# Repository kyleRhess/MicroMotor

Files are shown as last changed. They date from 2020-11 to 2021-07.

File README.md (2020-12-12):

# MicroMotor

## A three-phase BLDC motor driver with a rotary encoder interface and serial communication via USB.
## [More project details can be found here.](https://kylerhess.github.io/umotor.html)
\
 This code has been written for and tested on an ARM STM32F410 processor.
\
\
The rotary encoder interface was originally developed in my [EncoderQ](https://github.com/kyleRhess/EncoderQ) project.
\
\
The only rotary encoder that has been tested so far is the [Omron E6D-C](http://www.ia.omron.com/data_pdf/cat/e6d-c_ds_e_5_1_csm497.pdf).
\
\
The only BLDC motor that has been tested so far is the [Maxon EC 339268](https://www.maxongroup.com/medias/sys_master/root/8841185394718/EN-282.pdf). The motor requirement is that it must include Hall sensor output for position sensing. Back-EMF control is not currently supported.

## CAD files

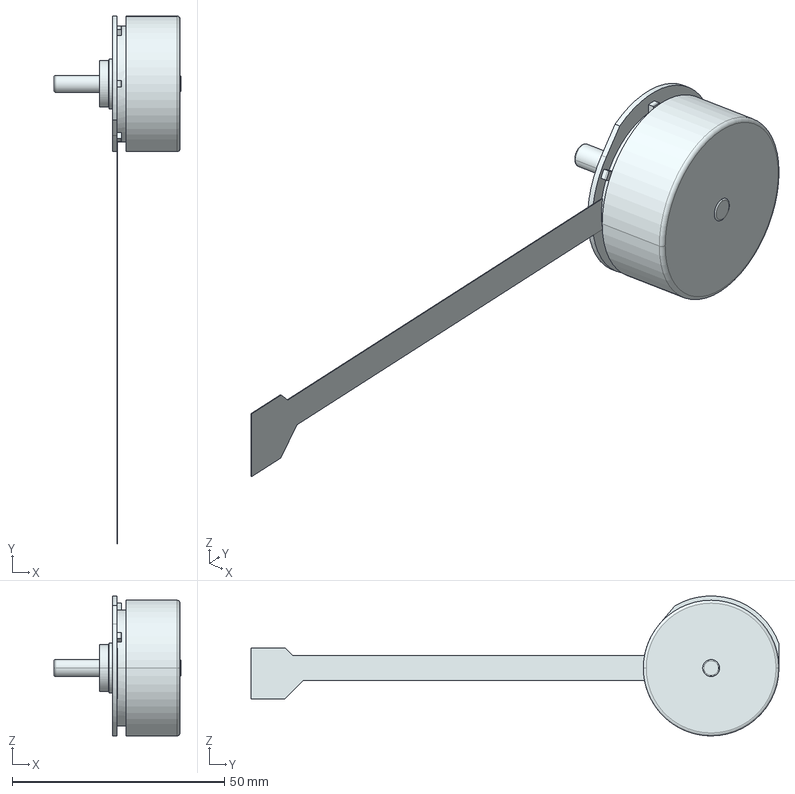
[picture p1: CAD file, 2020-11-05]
339267-ec32fl-15w-a/339267_ec32fl_15w_a.stp
29.9 x 124.5 x 33.0 mm

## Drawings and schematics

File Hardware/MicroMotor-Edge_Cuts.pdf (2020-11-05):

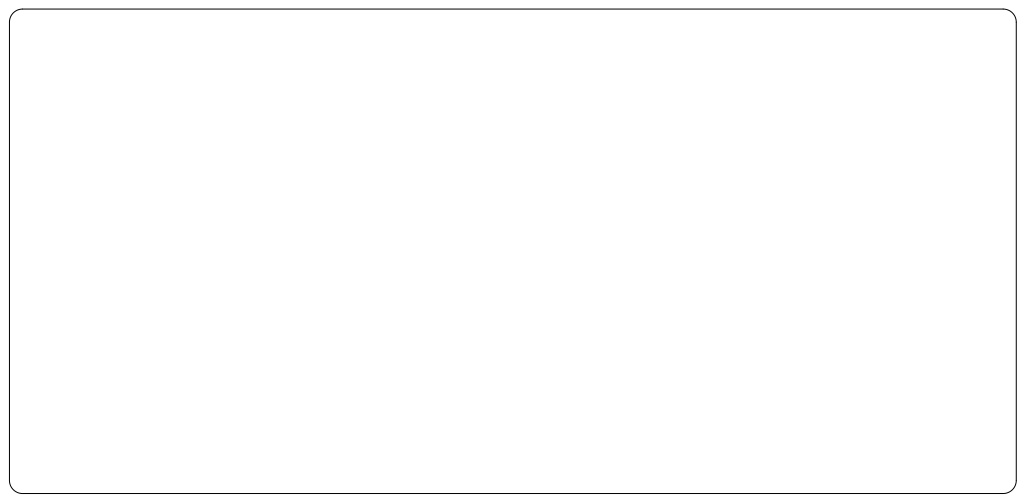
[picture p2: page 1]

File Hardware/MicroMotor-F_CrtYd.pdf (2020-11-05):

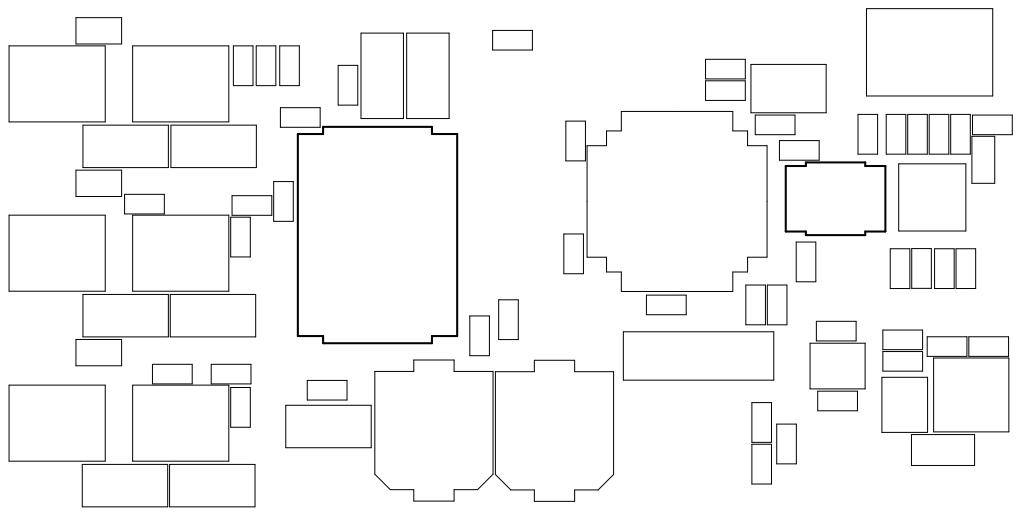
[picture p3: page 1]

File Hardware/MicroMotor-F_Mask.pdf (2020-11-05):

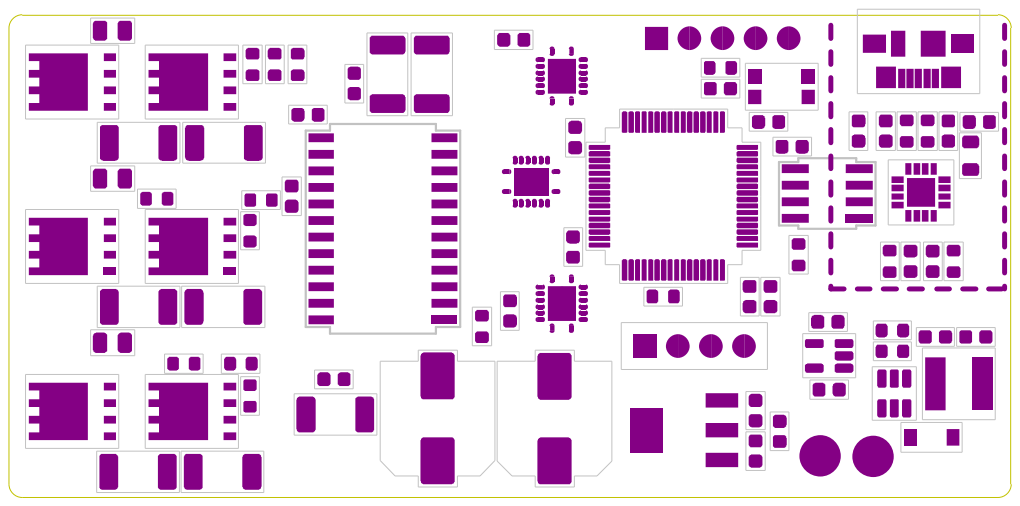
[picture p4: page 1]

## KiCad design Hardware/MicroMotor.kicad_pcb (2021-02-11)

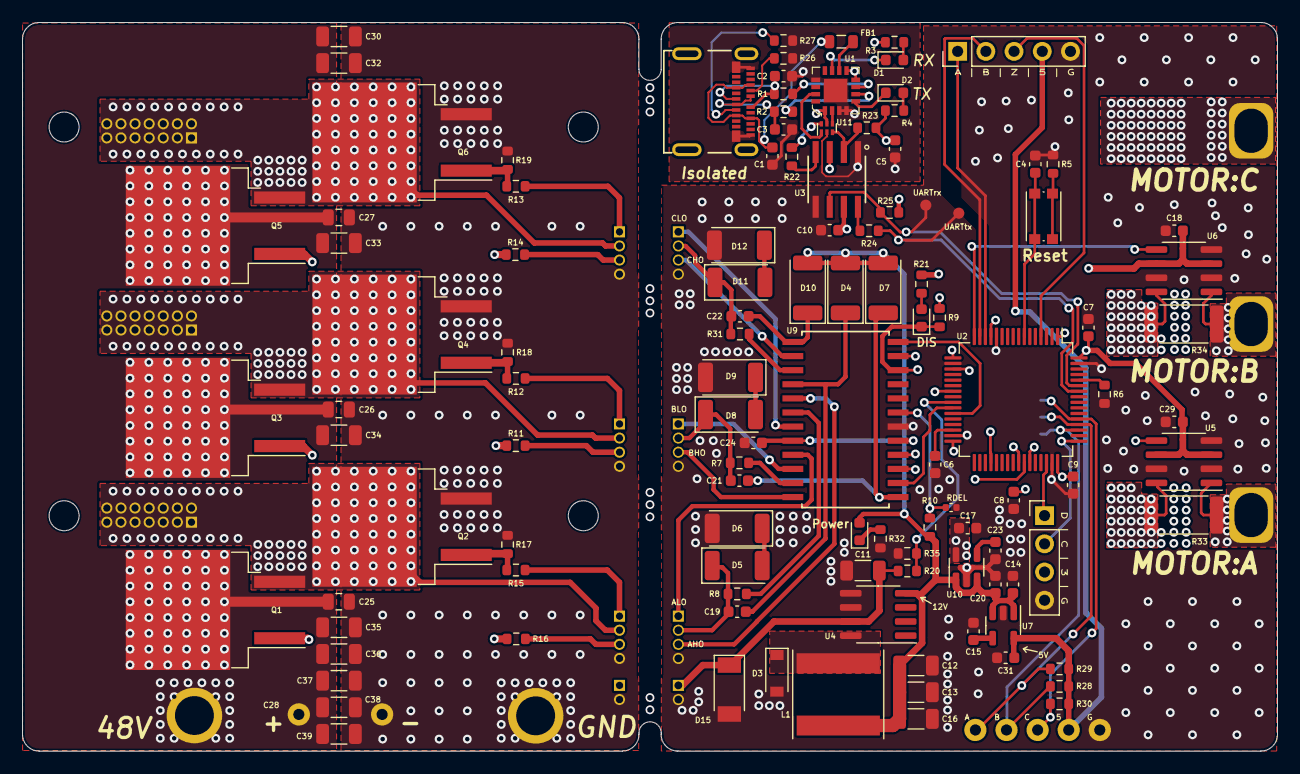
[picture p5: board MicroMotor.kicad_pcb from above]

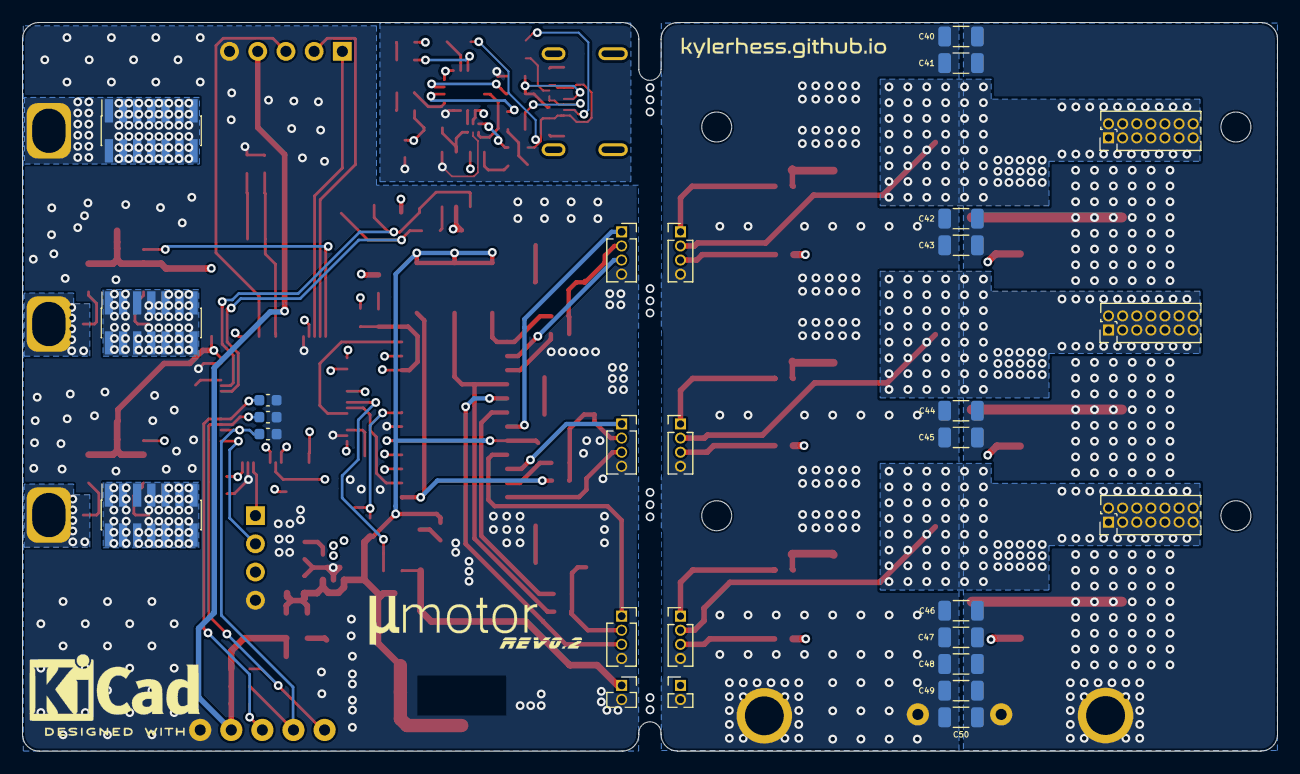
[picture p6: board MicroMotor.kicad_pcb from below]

Board: 4 copper layers, 113.0 x 65.6 mm, 149 parts (28 on the bottom side), 81 nets.

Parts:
5: TestPoint_Loop_D2.50mm_Drill1.0mm
48V: TestPoint_THTPad_D4.0mm_Drill2.0mm
A: TestPoint_Plated_Hole_D3.0mm
A#2: TestPoint_Loop_D2.50mm_Drill1.0mm
B: TestPoint_Plated_Hole_D3.0mm
B#2: TestPoint_Loop_D2.50mm_Drill1.0mm
C: TestPoint_Plated_Hole_D3.0mm
C1, C9, C15, C23: 10nF; C_0603_1608Metric
C2, C3: 47pF; C_0603_1608Metric
C4, C5, C8, C10, C18, C29: 0.1uF; C_0603_1608Metric
C6, C7: 2.2uF; C_0603_1608Metric
C11: 1uF; C_1206_3216Metric
C12, C13, C16: 47uF; C_1206_3216Metric
C14, C17, C20, C24, C31: 1uF; C_0603_1608Metric
C19, C21, C22: 0.22uF; C_0603_1608Metric
C25, C26, C27: 1uF; C_0805_2012Metric
C28: 1000uF; C_Radial_D18.0mm_H35.5mm_P7.50mm
C30, C32, C33, C34, C35, C36, C37, C38, C39, C40, C41, C42, C43, C44, C45, C46, C47, C48, C49, C50: 4.7uF; C_1206_3216Metric
C#2: TestPoint_Loop_D2.50mm_Drill1.0mm
D1, D2, D13, D14: LED; LED_0603_1608Metric
D3: 60V 500mA; D_SOD-123
D4, D5, D6, D7, D8, D9, D10, D11, D12: D; D_2010_5025Metric
D15: SMA6S56A; D_SOD-128
FB1: 1.5A; L_0805_2012Metric
G: TestPoint_Loop_D2.50mm_Drill1.0mm
GND: TestPoint_THTPad_D4.0mm_Drill2.0mm
J1: USB_C_Receptacle_USB2.0; USB_C_1054500101
J2: Conn_01x04_Male; PinHeader_1x04_P2.54mm_Vertical
J3: Conn_01x05_Male; PinHeader_1x05_P2.54mm_Vertical
J4, J5, J6: Conn_01x04_Male; PinHeader_1x04_P1.27mm_Vertical
J7, J8, J9: Conn_02x06_Odd_Even; PinHeader_2x07_P1.27mm_Vertical
J10, J11, J12: Conn_02x06_Odd_Even; PinSocket_2x07_P1.27mm_Vertical_SMD
J13, J14, J15: Conn_01x04_Female; PinSocket_1x04_P1.27mm_Vertical
J16: Conn_01x02_Male; PinHeader_1x02_P1.27mm_Vertical
J17: Conn_01x02_Female; PinSocket_1x02_P1.27mm_Vertical
L1: 100uH; L_Taiyo-Yuden_NR-80xx
Q1, Q2, Q3, Q4, Q5, Q6: FDB075N15A; TO-263-2
R1, R2: 27; R_0603_1608Metric
R3, R4, R21, R22, R24: 330; R_0603_1608Metric
R5: 470; R_0603_1608Metric
R6, R20, R28, R29, R30, R32: 10k; R_0603_1608Metric
R7, R8, R31: 1.2; R_0603_1608Metric
R9, R17, R18, R19: 100k; R_0603_1608Metric
R10: 50k; R_0603_1608Metric
R11, R12, R13, R14, R15, R16: 22; R_0603_1608Metric
R23, R25: 1k; R_0603_1608Metric
R26, R27: 5.1k; R_0603_1608Metric
R33, R34: 750u; R_2512_6332Metric
R35: 576; R_0603_1608Metric
RDEL: C_0402_1005Metric
SW1: SW_Push; SW_Push_1P1T_NO_CK_KMR2
U1: FT230XQ-T; WQFN-16-1EP_4x4mm
U2: STM32F410RBTx; LQFP-64_10x10mm_P0.5mm
U3: ACSL-6210-00RE
U4: LM2594HVM-12; SOIC-8_3.9x4.9mm_P1.27mm
U5, U6: INA240A3D; SOIC-8_3.9x4.9mm_P1.27mm
U7: LP2985-5.0; SOT-23-5
U9: HIP4086ABZ
U10: LP2985-3.3; SOT-23-5
U11: NC7WZ04; Fairchild_MicroPak-6_1.0x1.45mm_P0.5mm
UARTrx: TestPoint_Pad_D1.0mm
UARTtx: TestPoint_Pad_D1.0mm

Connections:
3v3Out: C5.1, R3.1, R4.1, R23.1, U1.1, U1.8, U1.9, U3.3, U11.5
5V_Out: 5.1, C31.2, J3.4, R28.2, R29.2, R30.2, U7.5
12V_Out: C12.2, C13.2, C14.2, C16.2, C20.2, C24.1, D4.2, D7.2, D10.2, D13.2, L1.2, R10.1, U4.4, U7.1, U7.3, U9.20, U10.1, U10.3
+3V3: C7.1, C8.1, C9.1, C10.1, C17.2, C18.2, C29.2, J2.3, R9.1, R21.1, R25.1, U2.1, U2.13, U2.19, U2.32, U2.48, U2.64, U3.7, U5.3, U5.6, U6.3, U6.6, U10.5
+48V: 48V.1, C11.2, C25.1, C26.1, C27.1, C28.1, C30.1, C32.1, C33.1, C34.1, C35.1, C36.1, C37.1, C38.1, C39.1, C40.1, C41.1, C42.1, C43.1, C44.1, C45.1, C46.1, C47.1, C48.1, C49.1, C50.1, D15.1, J16.1, J17.1, Q1.2, Q3.2, Q5.2, R20.2, U4.7
-RXD: U1.2, U11.4
/VBUS: C1.1, FB1.2, J1.A4, J1.A9, J1.B4, J1.B9
AHB: C19.1, D4.1, U9.16
AHI: U2.23, U9.5
AHO: Q1.1, R16.2
AHO_r: J6.3, J15.3, R16.1, U9.17
ALI: U2.41, U9.4
ALO: Q2.1, R15.2, R17.1
ALO_r: J6.1, J15.1, R15.1, U9.21
A_OUT: A.1, R33.1, U5.1
A_SENS: U2.17, U5.5
BHB: C21.1, D7.1, U9.1
BHI: U2.26, U9.2
BHO: Q3.1, R11.2
BHO_r: J5.3, J14.3, R11.1, U9.24
BLI: U2.42, U9.3
BLO: Q4.1, R12.2, R18.1
BLO_r: J5.1, J14.1, R12.1, U9.22
B_OUT: B.1, R34.1, U6.1
B_SENS: U2.16, U6.5
CHB: C22.1, D10.1, U9.13
CHI: U2.27, U9.12
CHO: Q5.1, R14.2
CHO_r: J4.3, J13.3, R14.1, U9.14
CLI: U2.43, U9.11
CLO: Q6.1, R13.2, R19.1
CLO_r: J4.1, J13.1, R13.1, U9.19
DIS: D14.1, R9.2, U2.36, U9.10
Encod_A: J3.1, U2.14
Encod_B: J3.2, U2.15
Encod_Z: J3.3, U2.4
GND: C4.2, C6.2, C7.2, C8.2, C9.2, C10.2, C11.1, C12.1, C13.1, C14.1, C15.1, C16.1, C17.1, C18.1, C20.1, C23.1, C24.2, C25.2, C26.2, C27.2, C28.2, C29.1, C30.2, C31.1, C32.2, C33.2, C34.2, C35.2, C36.2, C37.2, C38.2, C39.2, C40.2, C41.2, C42.2, C43.2, C44.2, C45.2, C46.2, C47.2, C48.2, C49.2, C50.2, D3.2, D6.2, D9.2, D12.2, D15.2, G.1, GND.1, J2.4, J3.5, J4.4, J5.4, J6.4, J13.4, J14.4, J15.4, J16.2, J17.2, Q2.3, Q4.3, Q6.3, R5.1, R6.1, R17.2, R18.2, R19.2, R32.1, R35.1, RDEL.2, U2.12, U2.18, U2.31, U2.47, U2.63, U3.5, U4.5, U4.6, U5.2, U5.4, U5.7, U6.2, U6.4, U6.7, U7.2, U9.6, U10.2
GNDS: C1.2, C2.2, C3.2, C5.2, J1.A1, J1.A12, J1.B1, J1.B12, R26.2, R27.2, U1.3, U1.4, U1.13, U1.17, U3.1, U11.2
HALL_A: A#2.1, R29.1, U2.52
HALL_B: B#2.1, R28.1, U2.51
HALL_C: C#2.1, R30.1, U2.53
MTR_A: C19.2, D5.1, J6.2, J9.1, J9.2, J9.3, J9.4, J9.5, J9.6, J9.7, J9.8, J9.9, J9.10, J9.11, J9.12, J9.13, J9.14, J12.1, J12.2, J12.3, J12.4, J12.5, J12.6, J12.7, J12.8, J12.9, J12.10, J12.11, J12.12, J12.13, J12.14, J15.2, Q1.3, Q2.2, R8.2, R33.2, U5.8
MTR_B: C21.2, D8.1, J5.2, J8.1, J8.2, J8.3, J8.4, J8.5, J8.6, J8.7, J8.8, J8.9, J8.10, J8.11, J8.12, J8.13, J8.14, J11.1, J11.2, J11.3, J11.4, J11.5, J11.6, J11.7, J11.8, J11.9, J11.10, J11.11, J11.12, J11.13, J11.14, J14.2, Q3.3, Q4.2, R7.2, R34.2, U6.8
MTR_C: C.1, C22.2, D11.1, J4.2, J7.1, J7.2, J7.3, J7.4, J7.5, J7.6, J7.7, J7.8, J7.9, J7.10, J7.11, J7.12, J7.13, J7.14, J10.1, J10.2, J10.3, J10.4, J10.5, J10.6, J10.7, J10.8, J10.9, J10.10, J10.11, J10.12, J10.13, J10.14, J13.2, Q5.3, Q6.2, R31.2
unnamed: C2.1, J1.A7, J1.B7, R1.1
unnamed: C3.1, J1.A6, J1.B6, R2.2
unnamed: C4.1, SW1.2, U2.7
unnamed: C6.1, U2.30
unnamed: C15.2, U7.4
unnamed: C23.2, U10.4
unnamed: D1.1, U1.11
unnamed: D1.2, R3.2
unnamed: D2.1, U1.5
unnamed: D2.2, R4.2
unnamed: D3.1, L1.1, U4.8
unnamed: D5.2, D6.1
unnamed: D8.2, D9.1
unnamed: D11.2, D12.1
unnamed: D13.1, R32.2
unnamed: D14.2, R21.2
unnamed: FB1.1, U1.10
unnamed: J1.A5, R26.1
unnamed: J1.B5, R27.1
unnamed: R1.2, U1.7
unnamed: R2.1, U1.6
unnamed: R5.2, SW1.1
unnamed: R6.2, U2.60
unnamed: R7.1, U9.23
unnamed: R8.1, U9.18
unnamed: R22.1, U3.4
unnamed: R22.2, U11.6
unnamed: R24.1, U3.8
unnamed: R31.1, U9.15
unnamed: U1.15, U11.1
RDEL: R10.2, RDEL.1, U9.7
RXD: R23.2, U3.2, U11.3
SWCLK: J2.2, U2.49
SWDIO: J2.1, U2.46
USART1_RX: R25.2, U2.59, U3.6, UARTrx.1
USART1_TX: R24.2, U2.58, UARTtx.1
VBAT_MEAS: R20.1, R35.2, U2.25

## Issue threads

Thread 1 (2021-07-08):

**Automation**

kyleRhess, 2021-07-08:
[Automatically move your cards](https://docs.github.com/articles/configuring-automation-for-project-boards/) to the right place based on the status and activity of your issues and pull requests.

Closed 2021-07-08.

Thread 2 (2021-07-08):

Increase Current Measurement Capability

kyleRhess, 2021-07-08:
- [ ] Change current sense amp to 20V/V gain.
- [ ] Change max output of current sense amp to 5V (divide this for 3.3 ADC)
- [ ] Change shunt resistor to 500 µΩ?

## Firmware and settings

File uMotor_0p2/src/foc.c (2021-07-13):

#include "foc.h"
#include "signal.h"

// =====================================
// Space Vector Modulation variables
// =====================================
static uint8_t sector_S 			= 255;
static uint8_t N 					= 255;
static float T0						= 0;
static float T1						= 0;
static float T2						= 0;
static float Ta						= 0;
static float Tb						= 0;
static float Tc						= 0;
static float m_i 					= 0;
static float m_j 					= 0;
static float m_k 					= 0;
#ifdef SINE_MODULATION
static float v_a 					= 0;
static float v_b 					= 0;
static float v_c 					= 0;
#endif

// =====================================
// Estimator variables
// =====================================
static float m_fDeltaT		 		= 0;

// =====================================
// Clarke & Park variables
// =====================================
static float i_a					= 0;
static float i_b					= 0;
static float i_c					= 0;
static float i_alpha 				= 0;
static float i_beta 				= 0;
static float v_d 					= 0;
static float v_q 					= 0;
static float v_alpha 				= 0;
static float v_beta 				= 0;

static ClockTimerus speedTimer;
static ClockTimerus speedTimerTrapz;

// =====================================
// EXTERNS
// =====================================

float m_fRotorThetaInit 			= 0;
float m_fRotorThetaNext 			= 0;
double m_fMechAngle					= 0.0f;
double m_fHomeOffset				= 0.0f;
double m_fMechAngleLast				= 0.0f;
float m_fCurrentA 					= 0.0f;
float m_fCurrentB 					= 0.0f;
float m_fCurrentC 					= 0.0f;
float m_fId 						= 0;
float m_fIq 						= 0;
float m_fSpeed						= 0;
float m_fRotorTheta					= 0.0f;
float m_fSpeedFilt					= 0;
float m_fSupplyVolt					= 0;
float m_fSupplyVoltInit				= 0;
float m_fThrotVolt					= 0;

float rotor_theta_init_L 			= 0;
int reversing 						= 0;
int a_state 						= 0;
int b_state 						= 0;
int c_state 						= 0;
double mechAngleoffset				= 0.0f;
float m_fTrapzPwmVal				= 0.0f;

float systemParams[256]				= {0};

PID_Controller pi_axis_d;
PID_Controller pi_axis_q;
PID_Controller pi_speed;
PID_Controller pi_pos;
PID_Controller pi_speed_trapz;

typedef struct FloatField
{
	uint8_t		beg; 			// 1
	uint32_t	timeUs; 		// 2
	float		torqueValue; 	// 3
	float		torqueReq;		// 4
	float		speedValue; 	// 5
	float		speedReq;		// 6
	float		posValue; 		// 7
	float		posReq;			// 8
	float		currentA;		// 9
	float		currentB;		// 10
	float		currentC;		// 11
	float		angle;			// 12
} __attribute__((__packed__)) FloatField;
static uint8_t uartTxBuff[128];
static FloatField txCmdData;


typedef struct lastvals
{
	float		angle;		// 11
	float		m_fMechAngle;			// 12
} lastvals;

#ifdef FAST_TRIG
static float sin_fast(float x);
static float cos_fast(float x);
#endif


static float rotorInit = 0.0f;
void FOC_Init(void)
{
	sector_S 				= 255;
	N 						= 255;
	T0						= 0;
	T1						= 0;
	T2						= 0;
	Ta						= 0;
	Tb						= 0;
	Tc						= 0;
	m_i 					= 0;
	m_j 					= 0;
	m_k 					= 0;
	#ifdef SINE_MODULATION
	v_a 					= 0;
	v_b 					= 0;
	v_c 					= 0;
	#endif
	m_fDeltaT 				= 0;
	m_fMechAngleLast		= 0.0f;
	m_fHomeOffset			= 0.0f;
	i_a						= 0;
	i_b						= 0;
	i_c						= 0;
	i_alpha 				= 0;
	i_beta 					= 0;
	v_d 					= 0;
	v_q 					= 0;
	v_alpha 				= 0;
	v_beta 					= 0;
	a_state 				= 0;
	b_state 				= 0;
	c_state 				= 0;
	m_fRotorThetaInit 		= 0;
	m_fRotorThetaNext 		= 0;
	m_fMechAngle			= 0.0f;
	m_fCurrentA 			= 0.0f;
	m_fCurrentB 			= 0.0f;
	m_fCurrentC 			= 0.0f;
	m_fId 					= 0;
	m_fIq 					= 0;
	m_fSpeed				= 0;
	m_fRotorTheta			= 0.0f;

	pi_axis_d.kP			= Kp;
	pi_axis_d.kI 			= Ki;
	pi_axis_d.kD 			= 0.0f;
	pi_axis_d.setPoint 		= 0.0f;
	pi_axis_d.deltaTime 	= (1.0f / PID_FREQ);

	pi_axis_q.kP 			= Kp;
	pi_axis_q.kI 			= Ki;
	pi_axis_q.kD 			= 0.0f;
	pi_axis_q.setPoint 		= 0.0f;
	pi_axis_q.deltaTime 	= (1.0f / PID_FREQ);

	pi_speed.kP 			= 0.05f;
	pi_speed.kI 			= 0.06f;
	pi_speed.kD 			= 0.0f;
	pi_speed.setPoint 		= 0.0f;
	pi_speed.deltaTime 		= (1.0f / 25.0f);

	pi_pos.kP 				= 30.0;
	pi_pos.kI 				= 0.0f;
	pi_pos.kD 				= 0.0f;
	pi_pos.setPoint 		= 0.0f;
	pi_pos.deltaTime 		= (1.0f / 50);

	pi_speed_trapz.kP 		= 0.01;
	pi_speed_trapz.kI 		= 0.005f;
	pi_speed_trapz.kD 		= 0.0f;
	pi_speed_trapz.setPoint = 0.0f;
	pi_speed_trapz.deltaTime= (1.0f / 25.0f);

	PID_Initialize(&pi_axis_d);
	PID_Initialize(&pi_axis_q);
	PID_Initialize(&pi_speed);
	PID_Initialize(&pi_pos);
	PID_Initialize(&pi_speed_trapz);

	pi_axis_d.windupMax 	= D_WIND;
	pi_axis_d.windupMin 	= -D_WIND;
	pi_axis_q.windupMax 	= Q_WIND;
	pi_axis_q.windupMin 	= -Q_WIND;
	pi_speed.windupMax 		= SPEED_WIND;
	pi_speed.windupMin 		= -SPEED_WIND;
	pi_pos.windupMax 		= POS_WIND;
	pi_pos.windupMin 		= -POS_WIND;
	pi_speed_trapz.windupMax= 0.5f;
	pi_speed_trapz.windupMin= 0;

	a_state = READ_H(HALL_A_PIN) && HALL_A_PIN;
	b_state = READ_H(HALL_B_PIN) && HALL_B_PIN;
	c_state = READ_H(HALL_C_PIN) && HALL_C_PIN;

	if(a_state == 1 && b_state == 0 && c_state == 0)
	{
		sector_S = 1;
		m_fRotorThetaInit = 0.0f;
	}
	else if(a_state == 1 && b_state == 1 && c_state == 0)
	{
		sector_S = 2;
		m_fRotorThetaInit = 60.0f;
	}
	else if(a_state == 0 && b_state == 1 && c_state == 0)
	{
		sector_S = 3;
		m_fRotorThetaInit = 120.0f;
	}
	else if(a_state == 0 && b_state == 1 && c_state == 1)
	{
		sector_S = 4;
		m_fRotorThetaInit = 180.0f;
	}
	else if(a_state == 0 && b_state == 0 && c_state == 1)
	{
		sector_S = 5;
		m_fRotorThetaInit = 240.0f;
	}
	else if(a_state == 1 && b_state == 0 && c_state == 1)
	{
		sector_S = 6;
		m_fRotorThetaInit = 300.0f;
	}

	rotor_theta_init_L 	= m_fRotorThetaInit;
	m_fRotorThetaNext 	= m_fRotorThetaInit;

	rotorInit = m_fRotorThetaInit;

	Clock_StartTimerUs(&speedTimer, 4000);
	Clock_StartTimerUs(&speedTimerTrapz, 40000);
}

void Run_SVM(void)
{
#if 1
	static float setPoint = 0;
	static int div = 0;
	div++;
	if(div >= 5 && Clock_GetMs() > 100)
	{
		div = 0;

		txCmdData.beg			= 0xAA;
		txCmdData.timeUs		= Clock_GetUs();
		txCmdData.angle 		= m_fRotorTheta;
		txCmdData.currentA 		= m_fCurrentA;
		txCmdData.currentB 		= m_fCurrentB;
		txCmdData.currentC 		= m_fCurrentC;
		txCmdData.posReq 		= pi_pos.setPoint;
		txCmdData.posValue		= (m_fMechAngle / 4.0);
		txCmdData.speedReq 		= setPoint;
		txCmdData.speedValue 	= m_fSpeed;
		txCmdData.torqueReq 	= pi_axis_q.setPoint;
		txCmdData.torqueValue 	= m_fIq;

		char str[128] = {0};
		sprintf(str, "%.3f,%.2f,%.2f,%.2f,%.2f,%08X,%.1f\n",
				m_fRotorTheta,
				m_fIq,
				pi_axis_q.setPoint,
				m_fCurrentA,
				m_fSupplyVolt,
				(unsigned int)Signal_GetMotorState(),
				Hall_GetRPM());

		uint8_t chars = 0;
		for (chars = 0; chars < sizeof(str)/sizeof(str[0]); ++chars)
		{
			if(str[chars] == '\n')
				break;
		}

		memcpy(&uartTxBuff[0], &str, chars+1);
		Serial_TxData2(uartTxBuff, chars+1);
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

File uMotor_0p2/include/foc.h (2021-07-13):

#ifndef FOC_H_ /* include guard */
#define FOC_H_

#include "system.h"

#define PI					3.141592654f
#define TWOPI				6.283185307f
#define FOURPI				12.566370614f
#define SHIFT_120			2.094395102f
#define SHIFT_240 			4.188790205f
#define _PI_3				1.047197551f    // pi / 3
#define	SQRT_3				1.732050808f    // sqrt(3)
#define SQR_THREE_TWO 		0.866025404f    // sqrt(3) / 2
#define ONE_THIRD			0.333333333f    // 1 / 3
#define ONE_SQR_THREE		0.577350269f    // 1 / sqrt(3)
#define	V_SUPPLY			48.0f		    //
#define	DEG_RAD				0.017453293f    // degrees to radians
#define ONE_2PI				0.159154943f    // 1 / (2pi)
#define PI_2				1.570796327f    // pi / 2

#define DPS_TO_RPM(xx)		((xx) / 6.0f)
#define MAX_SPEED			500.0f			// Maximum speed (RPM)
#define MAX_CURRENT			50.0f			// Maximum current per phase (A)

#define Q_WIND		        1.0f
#define D_WIND		        1.0f
#define SPEED_WIND	        (MAX_CURRENT * 0.1f) // amps
#define POS_WIND	        8000.0f // deg/s
#define Kp			        0.025f
#define Ki			        1.74399996f
#define PID_FREQ	        4000.0f	// Hz


#define POS_CONTROL
//#define SPD_CONTROL
//#define TRQ_CONTROL

//#define	FAST_TRIG
//#define	SINE_MODULATION

extern float m_fRotorThetaInit;
extern float m_fRotorThetaNext;
extern double m_fMechAngle;
extern double m_fHomeOffset;
extern double m_fMechAngleLast;
extern float m_fCurrentA;
extern float m_fCurrentB;
extern float m_fCurrentC;
extern float m_fId;
extern float m_fIq;
extern float m_fSpeed;
extern float m_fSpeedFilt;
extern double velest;
extern double velintegrator;
extern float m_fRotorTheta;
extern float m_fSupplyVolt;
extern float m_fSupplyVoltInit;
extern float m_fThrotVolt;


extern float rotor_theta_init_L;
extern int reversing;
extern int a_state;
extern int b_state;
extern int c_state;
extern double mechAngleoffset;

extern float m_fTrapzPwmVal;

extern float systemParams[256];

extern PID_Controller pi_axis_d;
extern PID_Controller pi_axis_q;
extern PID_Controller pi_speed;
extern PID_Controller pi_pos;;
extern PID_Controller pi_speed_trapz;




void FOC_Init(void);
void Run_SVM(void);

#endif /* FOC_H_ */

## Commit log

2020-11-06 Totally changed MOSFET layout. Added PWR and enabled LEDs
    [MicroMotor.kicad_pcb, MicroMotor.sch]
2020-11-07 Exposed hall nets for external use
    [MicroMotor.kicad_pcb]
2020-11-09 Added inverter logic to USB side since isolator inverts signals. Added pull-ups on optoisolator. Fix some silkscreens.
    [MicroMotor.csv, MicroMotor.kicad_pcb, MicroMotor.sch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]
2020-11-09 Ordered boards
    [MicroMotor.kicad_pcb]
2020-11-12 Initial firmware project made. Moved PCB files to Hardware directory.
    [MicroMotor-B_Cu.gbr, MicroMotor-B_Mask.gbr, MicroMotor-B_Paste.gbr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]
2020-12-03 Initial working firmware with hall ISR noise filtering.
    [hall.c, hall.h]
2020-12-14 More refactoring. Fixed fatal bug from previous refactoring. Working now.
    [clock.c, clock.h, hall.c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]
2020-12-26 Minor refactor of pwm.c
    [MicroMotor.kicad_pcb]
2021-01-16 Began mux remove and part consolidation
    [MicroMotor.kicad_pcb, MicroMotor.sch]
2021-01-22 Began making changes for 48V version.
    [MicroMotor.kicad_pcb, MicroMotor.sch]
2021-01-27 Nearly finished board and schematic changes for FOC and high current.
    [MicroMotor.kicad_pcb, MicroMotor.sch]
2021-02-02 Made board into pluggable two-board solution.
    [MicroMotor-B_Cu.gbr, MicroMotor-B_Mask.gbr, MicroMotor-B_Paste.gbr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]
2021-02-03 More board finalization. More low ESR caps on power stage. Silkscreen fixes.
    [MicroMotor.kicad_pcb, MicroMotor.sch]
2021-02-09 More board refinements
    [MicroMotor.kicad_pcb]
2021-02-11 Changed board connectors to 1.27mm pitch. Nearly done.
    [MicroMotor.kicad_pcb, MicroMotor.sch]
2021-02-11 Minor update to BOM
    [MicroMotor.kicad_pcb, MicroMotor.sch]
2021-02-11 Added UART pads
    [MicroMotor.kicad_pcb]
2021-02-11 Deleted extra pad
    [MicroMotor.kicad_pcb]
2021-03-11 Tuned torque/speed/position controllers. Working well... mostly...
2021-03-13 Moved FOC calc call to end of ADC complete ISR.
2021-03-17 Further code cleanup. Added homing feature. Started refactoring state monitor.
2021-03-20 Continued refactor. Noticed issue with rotor angle values growing too large. Floating point losing precision.
    [clock.c, foc.c, foc.h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]
2021-03-23 Minor clean up. Fixed potential clock overflow bug.
    [clock.c, clock.h, foc.c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]
2021-03-24 Minor refactoring. Switched PI controllers to use double precision floats. Same for rotor angle. This partially mitigates the issue with growing encoder values.
    [adc.h, foc.c, foc.h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]
2021-03-26 Further testing and optimization of PWM frequency to ensure timing is accurate.
2021-03-27 Fixed bug with speed calc that occurs when clock timer rolls over.
    [foc.c]
2021-05-23 Stopped receiving of UART bytes. Added support for throttle input. First test with bike, but wheel came off.
2021-06-20 Added missing timer init.
2021-07-13 Schematic PN update.
    [MicroMotor.sch]
2021-07-13 Updated current sense IC to 20V/V part.
    [MicroMotor.sch]
2021-07-13 Added tantalum cap to 12V reg.
    [MicroMotor.sch]
2021-07-13 Changed 5V linear reg to switching type.
    [MicroMotor.sch]
2021-07-13 Added filter caps to Hall sensor inputs.
    [MicroMotor.sch]

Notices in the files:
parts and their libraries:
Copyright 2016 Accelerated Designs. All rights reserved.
